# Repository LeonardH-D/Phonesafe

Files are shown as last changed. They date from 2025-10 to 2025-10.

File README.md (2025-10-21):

# Phonesafe
As many of us I have a (slight) smartphone addiction. To make it easier to withstand the distraction of it in lectures and working I designed this safe which is timer controlled and locks away your phone to get in the flow. 

A instructables with detailed building instructions will follow soon.

The code is written in the arduino IDE and still in beta. 

The box for the smartphone can be adjusted with Fusion 360 as the files are included. The attatched box is for an iPhone 15 Pro with a Mous Intralock case. 

In the PCB folder I uploaded the Gerber archive in Version 2. Version 2.1 will includes an external crystal for RTC will be uploaded soon. It will have the same dimensions as V2. 

The components are listed in the BOM. I sourced them in Germany at Reichelt and in China on Aliexpress. But all (exept the charging module) are pretty universally available, that should be no problem. Soldering is pretty straigth forward as is flashing the ESP. 

I hope you enjoy it and it helps you collect some phone free hours (maybe even days) :)

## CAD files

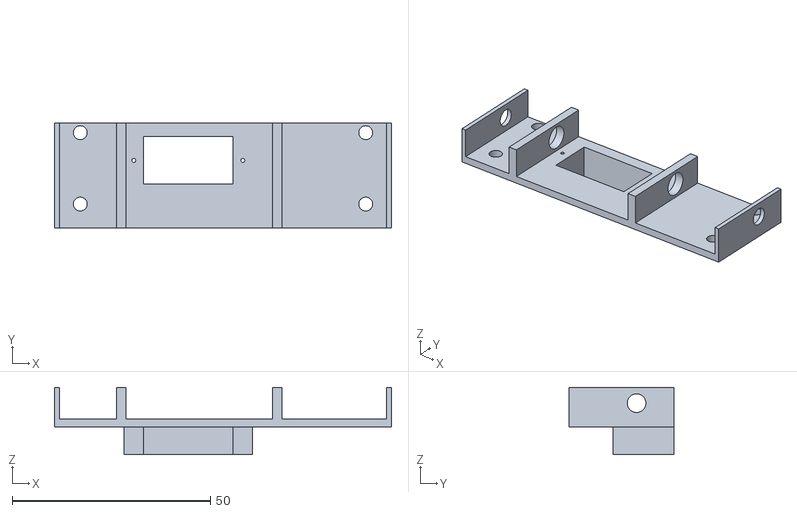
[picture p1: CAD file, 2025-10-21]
STLs/V2/Holder_Servo.stl
85.0 x 26.4 x 17.0

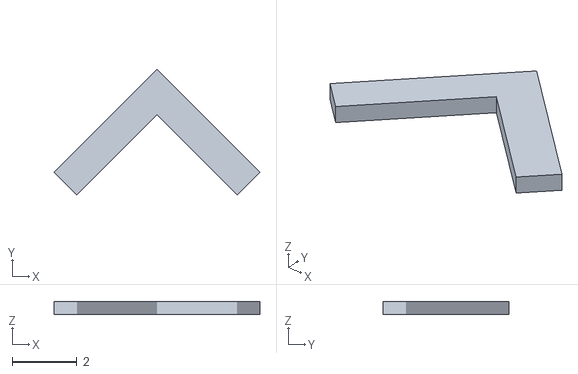
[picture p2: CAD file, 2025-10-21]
STLs/V2/Butto_UD_Arrow.stl
6.36 x 3.89 x 0.4

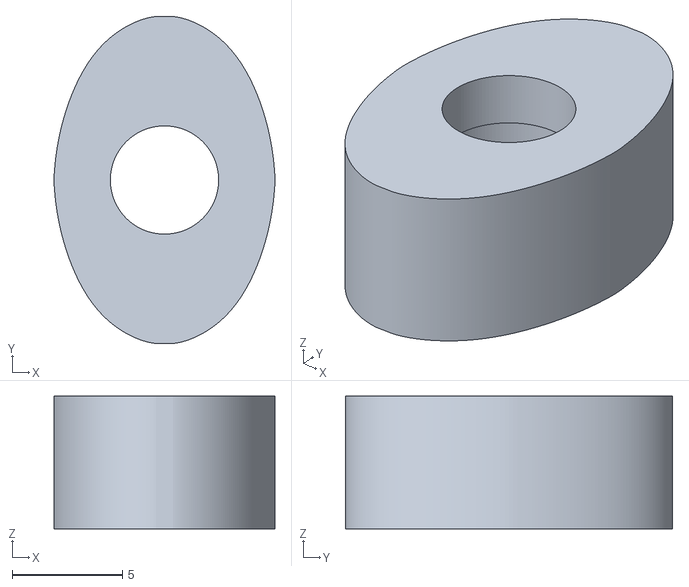
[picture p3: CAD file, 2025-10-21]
STLs/V2/Servo_Attachment.stl
10.0 x 14.8 x 6.00

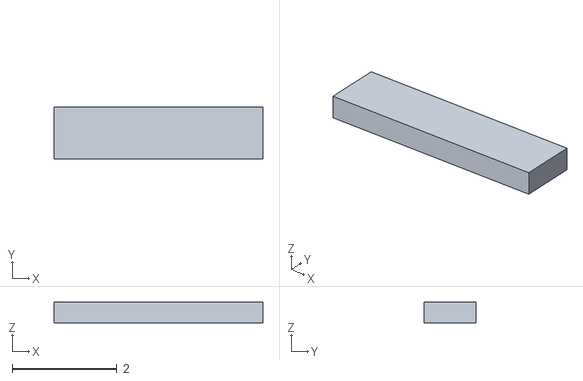
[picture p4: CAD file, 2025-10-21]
STLs/V2/Button_Menu_Up.stl
4.00 x 1.00 x 0.4

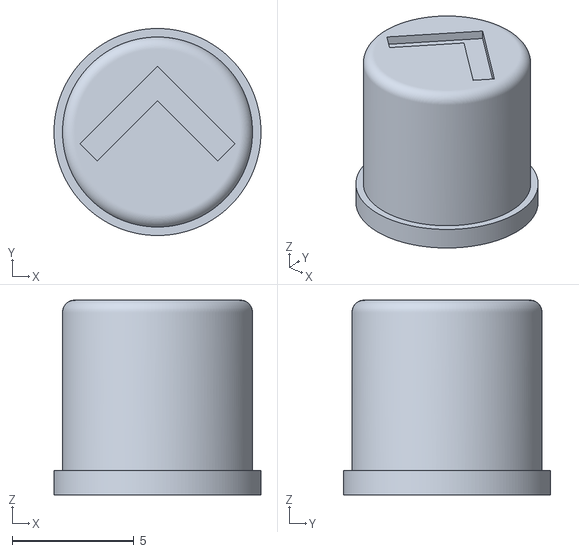
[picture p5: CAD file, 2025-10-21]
STLs/V2/Button_UD_Body.stl
8.50 x 8.50 x 8.00

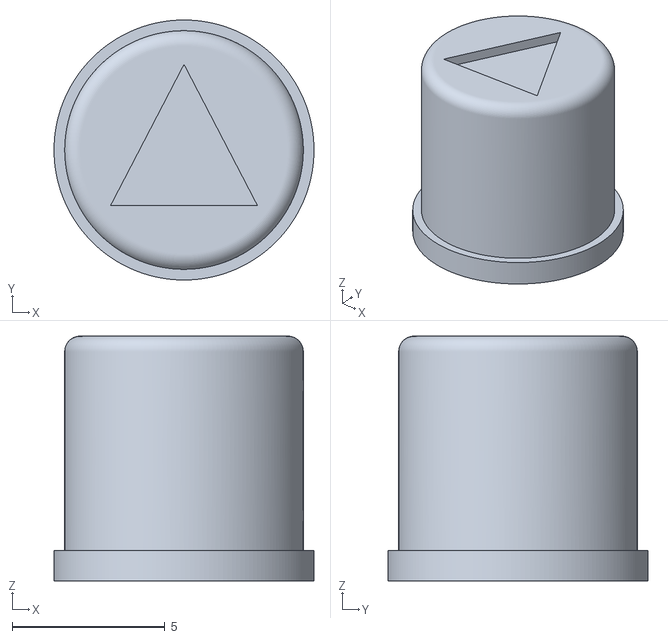
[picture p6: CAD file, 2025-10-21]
STLs/V2/Button_Start_Body.stl
8.50 x 8.50 x 8.00

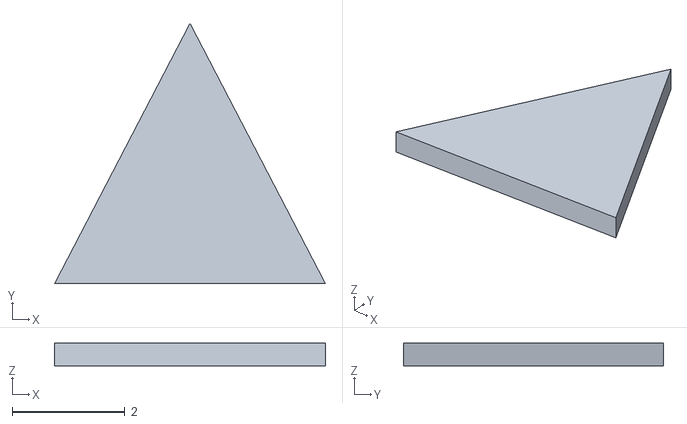
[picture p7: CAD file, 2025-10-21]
STLs/V2/Button_Start_Arrow.stl
4.80 x 4.61 x 0.4

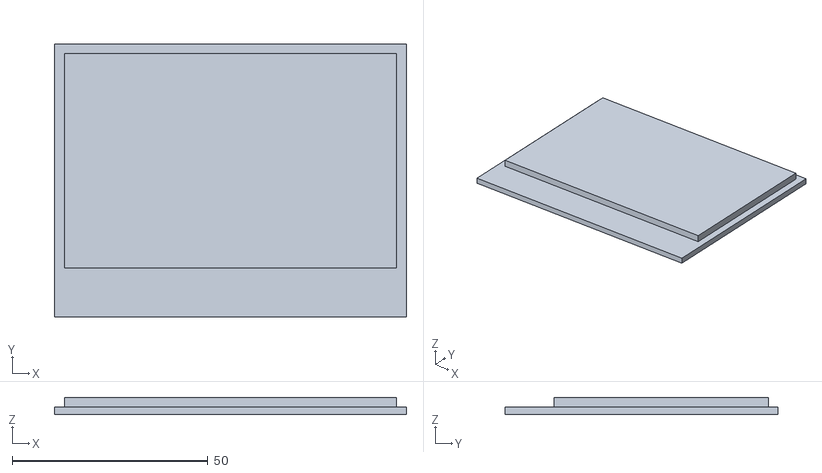
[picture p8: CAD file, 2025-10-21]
STLs/V2/Cover_PCB.stl
90.0 x 69.8 x 4.40

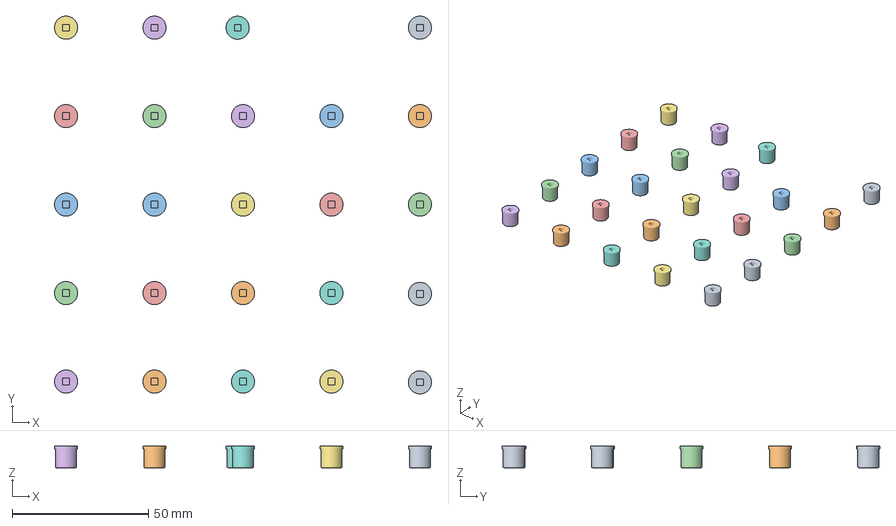
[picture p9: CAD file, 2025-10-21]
STLs/V2/Button_Menu_Body.3mf
138.5 x 138.8 x 8.00 mm
Knopf_Menu_Body x 6
Knopf_Start_Arrow x 6
Knopf_UD_Arrow x 12

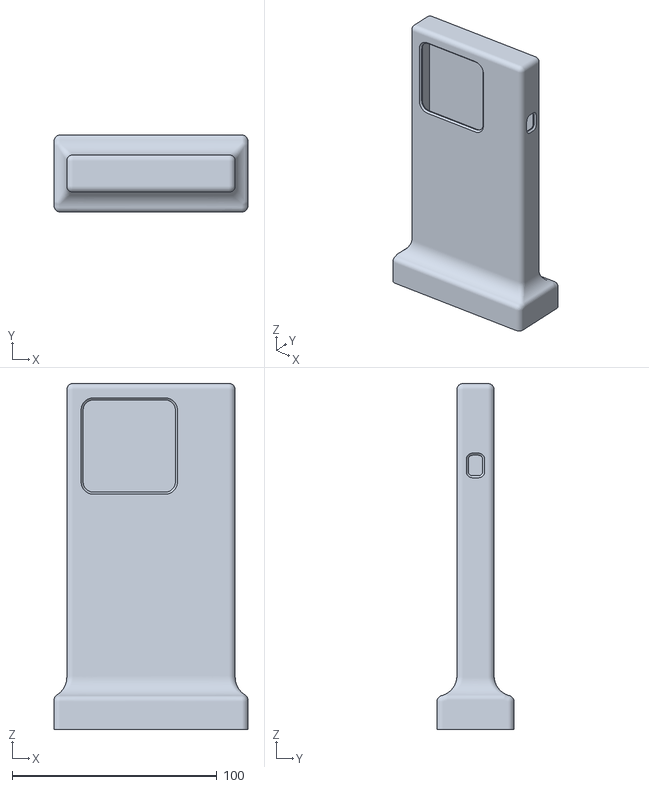
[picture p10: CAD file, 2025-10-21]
STLs/V2/Box_iP15P.stl
94.6 x 37.6 x 168.8

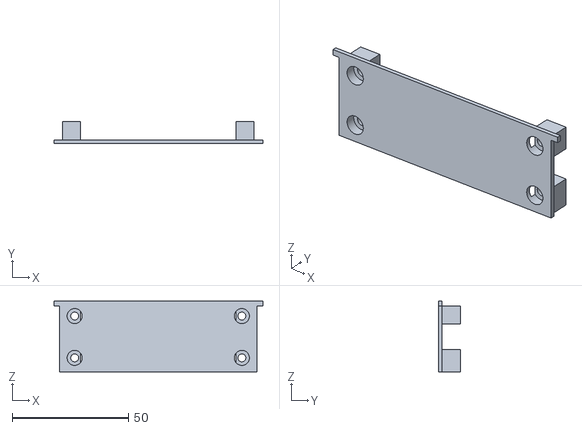
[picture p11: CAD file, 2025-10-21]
STLs/V2/Cover_locking_mechanism.stl
90.0 x 9.40 x 30.4

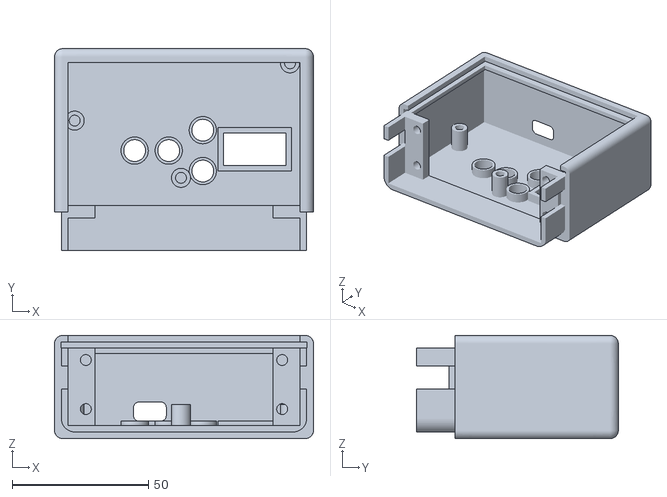
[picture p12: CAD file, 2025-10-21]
STLs/V2/Housing.stl
95.0 x 74.0 x 37.8

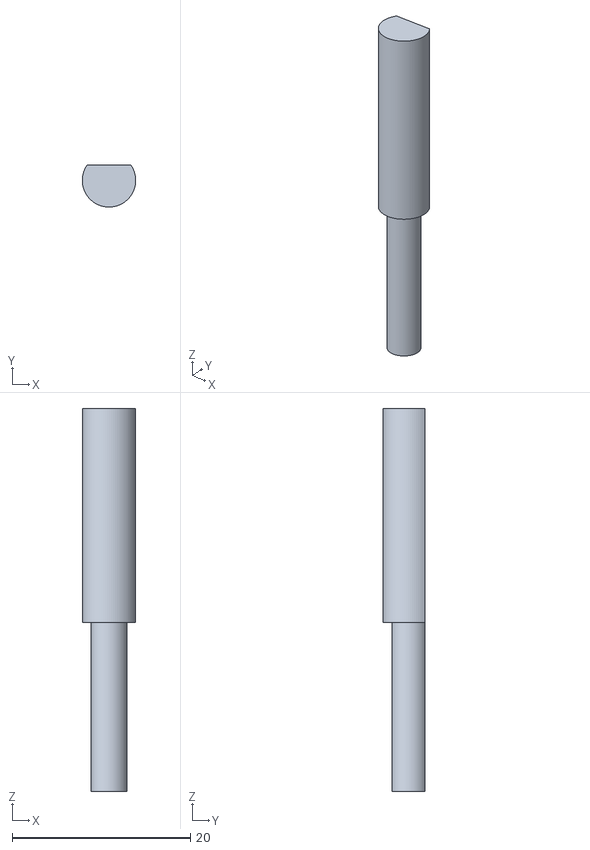
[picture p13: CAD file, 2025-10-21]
STLs/V2/Blockingbolt.stl
6.00 x 4.73 x 43.0

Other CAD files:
STLs/V2/Button_Menu_Middle.stl
STLs/V2/Button_Menu_Down.stl
STLs/V2/Button_Menu_Body.stl

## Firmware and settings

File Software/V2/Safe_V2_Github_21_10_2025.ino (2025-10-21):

#include <Wire.h>
#include "SSD1306Ascii.h"
#include "SSD1306AsciiWire.h"
#include <OneButton.h>
#include <ESP32Servo.h>
#include <Preferences.h>
#include <math.h>
#include "esp_sleep.h"
#include <WiFi.h>
#include <WebServer.h>
#include <time.h>
#include <sys/time.h>
#include <string.h>
#include <stdlib.h>
#include "driver/gpio.h"

// ============================================================================
//  External 32 kHz RTC clock – includes & guards
// ============================================================================
extern "C" {
  #if __has_include("rtc_clk.h")
    #include "rtc_clk.h"
  #endif
  #if __has_include("soc/rtc.h")
    #include "soc/rtc.h"
  #endif
}

// ============================================================================
//  Board / IO
// ============================================================================
#define LED_PIN (-1)         // disabled (SDA=8 is used for I2C on many C3 boards)
#define I2C_ADDRESS 0x3C
#define I2C_SDA 8
#define I2C_SCL 9

// Buttons
#define BTN_UP     5
#define BTN_DOWN   6
#define BTN_RESET  7
#define BTN_START  10

// Servo
#define SERVO_PIN 0

// Battery/VIN ADC pins (ESP32-C3 ADC1 channels)
#define BAT_ADC 1
#define VIN_ADC 2

// ============================================================================
//  Globals
// ============================================================================
SSD1306AsciiWire oled;
OneButton btnUp(BTN_UP, true);
OneButton btnDown(BTN_DOWN, true);
OneButton btnReset(BTN_RESET, true);
OneButton btnStart(BTN_START, true);
Servo myServo;
int servoPos = 0;
Preferences prefs;
WebServer server(80);

// Timer
const unsigned long MAX_SECONDS = 359999UL; // 99:59:59
unsigned long countdownSeconds = 0;
unsigned long originalDuration = 0;
unsigned long lastUpdate = 0;
bool running = false;

// Mode
enum LockMode : uint8_t { MODE_RELATIVE = 0, MODE_ABSOLUTE = 1 };
LockMode lockMode = MODE_RELATIVE;
time_t unlockAt = 0;            // target (epoch, today)
time_t lockStartedAt = 0;       // when locking started (for absolute mode)
bool timeIsSet = false;

// Stats
unsigned long totalReclaimed = 0;

// Fast increment
bool fastIncrementUp = false;
bool fastIncrementDown = false;
unsigned long lastIncrementUp = 0;
unsigned long lastIncrementDown = 0;

// Display
char lastDisplay[9] = "00:00:00";
const uint8_t COL_CENTER_REL = 16;
const uint8_t COL_CENTER_ABS = 34;

// Power / sleep
const unsigned long INACTIVITY_MS = 60000UL;
unsigned long lastInteractionMs = 0;
bool displayIsOn = true;

// Absolute target (today)
int absHour = 0;
int absMin  = 0;

// Battery / VIN
const float R1 = 100000.0f, R2 = 100000.0f;
const float VOLT_DIV = (R1 + R2) / R2; // 2.0
const float CAL = 1.00f;
const unsigned long BATT_INTERVAL_MS = 3000;
const int BATT_SAMPLES = 12;
unsigned long lastBattMs = 0;
float lastBattV = -1.0f;
int lastBattPct = -1;

const float VR1 = 100000.0f, VR2 = 100000.0f;
const float VOLT_DIV_VIN = (VR1 + VR2) / VR2; // 2.0
const float CAL_VIN = 1.00f;
const unsigned long VIN_INTERVAL_MS = 2000;
const int VIN_SAMPLES = 10;
unsigned long lastVinMs = 0;
float lastVin = -1.0f;

// Charging detection interval (actual VIN in volts)
const float VIN_CHARGE_MIN = 3.30f;  // lower bound (e.g., node 1.7 V with 1:1 divider)
const float VIN_CHARGE_MAX = 5.6f;  // upper bound (protect against noise / mis-wire)
bool lastChargingShown = false;
bool isChargingNow = false;
float lastVinDisplay = 0.0f;  // Debug: store last measured VIN for OLED

// Menu
bool showMenu = false;
int menuIndex = 0;              // 0=Stats, 1=About, 2=Mode, 3=Clock, 4=Setup Portal
const int MENU_COUNT = 5;

// Persistence
const uint32_t CONFIG_MAGIC = 0xC0FFEE11;

// Wi-Fi / NTP
char wifiSsid[33] = {0};
char wifiPass[65] = {0};

int   lastNtpSyncYday   = -1;
time_t lastNtpSyncEpoch = 0;

const char* NTP_SERVER1 = "pool.ntp.org";
const char* TZ_STR      = "CET-1CEST,M3.5.0/2,M10.5.0/3";

// Preference keys
const char* KEY_WIFI_SSID = "wifi_ssid";
const char* KEY_WIFI_PASS = "wifi_pass";
const char* KEY_NTP_YDAY  = "ntp_yday";
const char* KEY_NTP_EPOCH = "ntp_epoch";
const char* KEY_LOCKSTART = "lockStart";     // persist lockStartedAt

// AP / Web
bool portalActive = false;
unsigned long portalStartedMs = 0;
const unsigned long PORTAL_TIMEOUT_MS = 300000UL;
const char* AP_SSID = "SafeSetup";
const char* AP_PASS = "12345678";

// External 32 kHz
bool ext32k_ok = false;

// ============================================================================
//  Prototypes
// ============================================================================
void enableExternal32K();
void noteInteraction();
void oledDisplayOn();
void oledDisplayOff();
void setupLightSleepWakePins();
void maybeEnterLightSleep();
void lockServo();
void unlockServo();

void clearRows(uint8_t row_from, uint8_t rows);
void print2XBlock(uint8_t rowTop, uint8_t col, const char* txt);
void displayMainHeader(int pct);
void displayTimeRel(bool force);
void displayTimeAbs(bool force);
void displayChargingLine();

float readBatteryVoltage();
float readVinVoltage();
int liionPercentFromVoltage(float v);

void showStatsPage();
void showMainPage();
void showAboutPage();
void showModePage();
void showClockPage();
void showPortalPage();
void renderMenuPage();


void startTimePortal();
void stopTimePortal();
void handleRoot();
void handleSet();
void handleWifi();

void setSystemEpoch(time_t nowEpoch);
time_t nowEpoch();

void absInitFromNowOrUnlock();
void absClampToToday();
time_t absMakeEpochToday();
void absAdjustMinutes(int delta);

void applyDefaultsAndSave(bool keepTotal);
void saveState();
void loadState();

void loadWifiCreds();
void saveWifiCreds();
bool connectWifiSTA(uint32_t timeoutMs);
bool syncTimeViaNtp(uint32_t waitMs);
void disconnectWifi();
void maybeHourlyNtpSync();

// ============================================================================
//  External 32 kHz
// ============================================================================
void enableExternal32K() {
#if defined(RTC_SLOW_FREQ_32K_XTAL) && defined(RTC_PLL_FREQ_480M)
  #if __has_include("rtc_clk.h")
    rtc_clk_32k_enable(true);
    bool stable = false;
    for (int i = 0; i < 200; ++i) {
      if (rtc_clk_32k_enabled()) { stable = true; break; }
      delay(10);
    }
    if (stable) {
      rtc_clk_slow_freq_set(RTC_SLOW_FREQ_32K_XTAL);
      ext32k_ok = true;
    } else {
      rtc_clk_32k_enable(false);
      rtc_clk_slow_freq_set(RTC_SLOW_FREQ_RTC);
      ext32k_ok = false;
    }
  #endif
#else
  ext32k_ok = false;
#endif
}

// ============================================================================
//  Web portal HTML (English)
// ============================================================================
const char PAGE_HTML[] PROGMEM = R"HTML(
<!doctype html><meta name=viewport content="width=device-width,initial-scale=1">
<title>Safe Setup Portal</title>
<style>
  body{font-family:sans-serif;margin:20px;max-width:560px}
  button,input{font-size:1rem;padding:.5rem .7rem}
  label{display:block;margin:.4rem 0 .2rem}
  .card{border:1px solid #ddd;border-radius:8px;padding:12px;margin:14px 0}
  .row{display:flex;gap:8px;align-items:center}
</style>

<h2>System Time & Wi-Fi</h2>

<div class=card>
  <h3>Set System Time</h3>
  <p>This only sets the internal clock.</p>
  <button onclick="sendNow()">Use device time</button>
  <span id=resp style="margin-left:10px"></span>
</div>

<div class=card>
  <h3>Save Home Wi-Fi (for automatic hourly NTP sync)</h3>
  <label>SSID</label>
  <input id=ssid placeholder="Wi-Fi name" maxlength=32>
  <label>Password</label>
  <input id=pass type=password placeholder="Wi-Fi password" maxlength=64>
  <div class=row style="margin-top:.6rem">
    <button onclick="saveWifi()">Save</button>
    <span id=wifiResp></span>
  </div>
  <p style="font-size:.9rem;color:#555">Credentials are stored locally on the device.</p>
</div>

<script>
function epochSec(d){return Math.floor(d.getTime()/1000);}
function sendNow(){
  const now=epochSec(new Date());
  fetch('/set?now='+now).then(r=>r.text()).then(t=>{document.getElementById('resp').textContent=t}).catch(e=>alert(e));
}
function saveWifi(){
  const s=document.getElementById('ssid').value.trim();
  const p=document.getElementById('pass').value;
  fetch('/wifi?ssid='+encodeURIComponent(s)+'&pass='+encodeURIComponent(p))
    .then(r=>r.text()).then(t=>{document.getElementById('wifiResp').textContent=t})
    .catch(e=>alert(e));
}
</script>
)HTML";

// ============================================================================
//  Absolute mode helpers (today)
// ============================================================================
void absInitFromNowOrUnlock() {
  time_t now = nowEpoch();
  if (!timeIsSet || now <= 0) { absHour = 22; absMin = 0; return; }
  struct tm tmNow; localtime_r(&now, &tmNow);
  if (unlockAt > now) {
    struct tm tmTgt; time_t tgt=unlockAt; localtime_r(&tgt, &tmTgt);
    absHour = (tmTgt.tm_yday==tmNow.tm_yday)? tmTgt.tm_hour : tmNow.tm_hour;
    absMin  = (tmTgt.tm_yday==tmNow.tm_yday)? tmTgt.tm_min  : tmNow.tm_min;
  } else {
    absHour = tmNow.tm_hour; absMin = tmNow.tm_min;
  }
}

void absClampToToday() {
  time_t now = nowEpoch();
  if (!timeIsSet || now <= 0) {
    if (absHour < 0) absHour = 0;
    if (absHour > 23) absHour = 23;
    if (absMin  < 0) absMin  = 0;
    if (absMin  > 59) absMin  = 59;
    return;
  }
  struct tm tmNow; localtime_r(&now, &tmNow);
  int nowM = tmNow.tm_hour*60 + tmNow.tm_min;
  int tgtM = absHour*60 + absMin;
  if (tgtM < nowM) tgtM = nowM;
  if (tgtM > 23*60 + 59) tgtM = 23*60 + 59;
  absHour = tgtM / 60;
  absMin  = tgtM % 60;
}

time_t absMakeEpochToday() {
  time_t now = nowEpoch(); if (now <= 0) return 0;
  struct tm t; localtime_r(&now,&t);
  t.tm_sec = 0; t.tm_hour = absHour; t.tm_min  = absMin;
  return mktime(&t);
}

void absAdjustMinutes(int delta) {
  int tgtM = absHour*60 + absMin + delta;
  if (tgtM < 0) tgtM = 0;
  if (tgtM > 23*60 + 59) tgtM = 23*60 + 59;
  absHour = tgtM / 60;
  absMin  = tgtM % 60;
  absClampToToday();
}

// ============================================================================
//  Defaults / Persistence
// ============================================================================
void applyDefaultsAndSave(bool keepTotal) {
  unsigned long keepTotalVal = keepTotal ? prefs.getULong("total", 0UL) : 0UL;
  countdownSeconds = 0;
  originalDuration = 0;
  running = false;
  unlockAt = 0;
  lockStartedAt = 0;   // reset
  timeIsSet = false;
  lockMode = MODE_RELATIVE;
  servoPos = 0;
  totalReclaimed = keepTotalVal;
  absHour = 22; absMin = 0;
  prefs.putUInt("magic", CONFIG_MAGIC);
  saveState();
}

void saveState() {
  prefs.putULong("remain", countdownSeconds);
  prefs.putULong("orig", originalDuration);
  prefs.putBool("running", running);
  prefs.putULong("total", totalReclaimed);
  prefs.putUChar("srvpos", (uint8_t)servoPos);

  prefs.putUChar("mode", (uint8_t)lockMode);
  prefs.putULong("unlockAt", (uint32_t)unlockAt);
  prefs.putBool("timeSet", timeIsSet);
  prefs.putUInt("magic", CONFIG_MAGIC);

  // persist absolute-mode start
  prefs.putULong(KEY_LOCKSTART, (uint32_t)lockStartedAt);
}

void loadState() {
  countdownSeconds = prefs.getULong("remain", 0UL);
  originalDuration = prefs.getULong("orig", 0UL);
  running = prefs.getBool("running", false);
  totalReclaimed = prefs.getULong("total", 0UL);
  servoPos = (int)prefs.getUChar("srvpos", 0);

  lockMode = (LockMode)prefs.getUChar("mode", (uint8_t)MODE_RELATIVE);
  unlockAt = (time_t)prefs.getULong("unlockAt", 0UL);
  timeIsSet = prefs.getBool("timeSet", false);

  // restore absolute-mode start
  lockStartedAt = (time_t)prefs.getULong(KEY_LOCKSTART, 0UL);
}

// ============================================================================
//  Time helpers
// ============================================================================
void setSystemEpoch(time_t t) {
  struct timeval tv = { t, 0 };
  settimeofday(&tv, nullptr);
  timeIsSet = (t > 1600000000L);
}

time_t nowEpoch() { return time(nullptr); }

// ============================================================================
//  Wi-Fi / NTP
// ============================================================================
void loadWifiCreds() {
  String s = prefs.getString(KEY_WIFI_SSID, "");
  String p = prefs.getString(KEY_WIFI_PASS, "");
  memset(wifiSsid, 0, sizeof(wifiSsid));
  memset(wifiPass, 0, sizeof(wifiPass));
  s.toCharArray(wifiSsid, sizeof(wifiSsid));
  p.toCharArray(wifiPass, sizeof(wifiPass));
  lastNtpSyncYday  = (int)prefs.getInt(KEY_NTP_YDAY, -1);
  lastNtpSyncEpoch = (time_t)prefs.getULong(KEY_NTP_EPOCH, 0UL);
}

void saveWifiCreds() {
  prefs.putString(KEY_WIFI_SSID, wifiSsid);
  prefs.putString(KEY_WIFI_PASS, wifiPass);
}

bool connectWifiSTA(uint32_t timeoutMs) {
  if (wifiSsid[0] == '\0') return false;
  WiFi.mode(WIFI_STA);
  WiFi.begin(wifiSsid, wifiPass);
  uint32_t start = millis();
  while (WiFi.status() != WL_CONNECTED && millis() - start < timeoutMs) {
    delay(100);
  }
  return WiFi.status() == WL_CONNECTED;
}

bool syncTimeViaNtp(uint32_t waitMs) {
  // Timezone-safe NTP
  configTzTime(TZ_STR, NTP_SERVER1);

  uint32_t start = millis();
  time_t now = 0;
  do {
    delay(200);
    now = time(nullptr);
  } while ((now < 1600000000L) && (millis() - start < waitMs));

  if (now >= 1600000000L) {
    // Ensure TZ stays applied
    setenv("TZ", TZ_STR, 1);
    tzset();

    struct timeval tv = { now, 0 };
    settimeofday(&tv, nullptr);
    timeIsSet = true;
    lastNtpSyncEpoch = now;
    prefs.putULong(KEY_NTP_EPOCH, (uint32_t)lastNtpSyncEpoch);
    return true;
  }
  return false;
}

void disconnectWifi() {
  if (WiFi.getMode() != WIFI_OFF) {
    WiFi.disconnect(true);
    WiFi.mode(WIFI_OFF);
  }
}

// Hourly auto NTP sync (first 5 minutes each hour)
void maybeHourlyNtpSync() {
  static unsigned long lastCheckMs = 0;
  if (millis() - lastCheckMs < 30000UL) return;  // throttle our own CPU usage
  lastCheckMs = millis();

  // If you want to allow sync while locked, remove "|| running" below.
  if (portalActive /*|| running*/) return; 
  if (wifiSsid[0] == '\0') return;

  time_t now = nowEpoch();
  if (now <= 0) return;

  // Try if it's been an hour since last success
  if (lastNtpSyncEpoch > 0 && (now - lastNtpSyncEpoch) < 3600) return;

  // Bring up Wi-Fi briefly, sync, then go back down
  if (connectWifiSTA(8000)) {
    if (syncTimeViaNtp(8000)) {
      // Update "last sync" markers
      struct tm tmNow; localtime_r(&now, &tmNow);
      lastNtpSyncEpoch = now;
      lastNtpSyncYday = tmNow.tm_yday;
      prefs.putULong(KEY_NTP_EPOCH, (uint32_t)lastNtpSyncEpoch);
      prefs.putInt(KEY_NTP_YDAY, lastNtpSyncYday);
      saveState();
    }
    disconnectWifi();
  }
}

// ============================================================================
//  AP / Web
// ============================================================================
void startTimePortal() {
  if (portalActive) return;
  WiFi.mode(WIFI_AP);
  WiFi.softAP(AP_SSID, AP_PASS);
  delay(200);
  server.on("/", handleRoot);
  server.on("/set", handleSet);
  server.on("/wifi", handleWifi);
  server.begin();
  portalActive = true;
  portalStartedMs = millis();
  displayIsOn = true; oledDisplayOn();
}
void stopTimePortal() {
  if (!portalActive) return;
  server.stop();
  WiFi.softAPdisconnect(true);
  WiFi.mode(WIFI_OFF);
  portalActive = false;
}
void handleRoot() { server.send(200, "text/html", PAGE_HTML); }
void handleSet() {
  time_t now = server.hasArg("now") ? (time_t)server.arg("now").toInt() : 0;
  if (now > 1600000000L) {
    setSystemEpoch(now);
    prefs.putULong(KEY_NTP_EPOCH, (uint32_t)now);
    server.send(200, "text/plain", "System time set!");
  } else {
    server.send(400, "text/plain", "Invalid time");
  }
}
void handleWifi() {
  String ssid = server.hasArg("ssid") ? server.arg("ssid") : "";
  String pass = server.hasArg("pass") ? server.arg("pass") : "";
  ssid.trim();
  if (ssid.length() == 0) { server.send(400, "text/plain", "SSID missing"); return; }
  if (ssid.length() > 32 || pass.length() > 64) { server.send(400, "text/plain", "Too long"); return; }
  memset(wifiSsid, 0, sizeof(wifiSsid));
  memset(wifiPass, 0, sizeof(wifiPass));
  ssid.toCharArray(wifiSsid, sizeof(wifiSsid));
  pass.toCharArray(wifiPass, sizeof(wifiPass));
  saveWifiCreds();
  server.send(200, "text/plain", "Wi-Fi saved");
}

// ============================================================================
//  OLED helpers & pages
// ============================================================================
void clearRows(uint8_t row_from, uint8_t rows) {
  oled.set1X();
  for (uint8_t r = 0; r < rows; r++) {
    oled.setCursor(0, row_from + r);
    oled.print("                              ");
  }
}
void print2XBlock(uint8_t rowTop, uint8_t col, const char* txt) {
  clearRows(rowTop, 2);
  oled.set2X();
  oled.setCursor(col, rowTop);
  oled.print(txt);
  oled.set1X();
}

void displayChargingLine() {
  clearRows(7, 1);
  oled.set1X();
  oled.setCursor(0, 7);

  if (isChargingNow) {
    oled.printf("Charging", lastVinDisplay);
  } 
}

void displayMainHeader(int pct) {
  clearRows(1, 1);
  oled.set1X(); oled.setCursor(0,1);
  if (lockMode==MODE_RELATIVE) {
    oled.printf("%d%% | Timer", pct);
  } else {
    oled.printf("%d%% | Opens at...", pct);
  }
}
void displayTimeRel(bool forceUpdate) {
  unsigned long seconds = countdownSeconds;
  if (seconds > MAX_SECONDS) seconds = MAX_SECONDS;
  unsigned int h = seconds / 3600UL; seconds %= 3600UL;
  unsigned int m = seconds / 60UL;   unsigned int s = seconds % 60UL;
  char buf[9]; snprintf(buf, sizeof(buf), "%02u:%02u:%02u", h, m, s);
  if (forceUpdate || strcmp(buf, lastDisplay) != 0) {
    print2XBlock(3, COL_CENTER_REL, buf);
    strcpy(lastDisplay, buf);
  }
  clearRows(5,1);
  displayChargingLine();
}
void displayTimeAbs(bool force) {
  static int lastHr=-1, lastMin=-1; static bool lastRun=false;
  if (force || lastHr!=absHour || lastMin!=absMin || lastRun!=running) {
    char value[16]; snprintf(value,sizeof(value),"%02d:%02d", absHour, absMin);
    print2XBlock(3, COL_CENTER_ABS, value);
    lastHr=absHour; lastMin=absMin; lastRun=running;
  }
  clearRows(5,1);
  displayChargingLine();
}


void showStatsPage() {
  oled.clear();
  
  // use smaller font (4x6)
  oled.setFont(System5x7);   // default small readable font
  oled.set1X();
  
  oled.setCursor(0, 0);
  oled.println("Stats");
  oled.setCursor(0, 2);
  oled.println("Total time saved:");

  unsigned long total = totalReclaimed;
  unsigned long days  = total / 86400UL;
  unsigned long rem   = total % 86400UL;
  unsigned int  hours = rem / 3600UL;
  unsigned int  mins  = (rem % 3600UL) / 60UL;

  // draw in smaller size (1X) — no double-size here
  oled.setCursor(0, 4);
  oled.printf("%03lu days", days);
  oled.setCursor(0, 5);
  oled.printf("%02u hours", hours);
  oled.setCursor(0, 6);
  oled.printf("%02u mins", mins);

  // Always show VIN/charging line on bottom
  displayChargingLine();

  // Restore normal font for next pages
  oled.setFont(Adafruit5x7);
}
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
void loop() {
  btnUp.tick(); btnDown.tick(); btnReset.tick(); btnStart.tick();

  if (digitalRead(BTN_UP)==LOW || digitalRead(BTN_DOWN)==LOW ||
      digitalRead(BTN_RESET)==LOW || digitalRead(BTN_START)==LOW) {
    noteInteraction();
  }

  if (portalActive) {
    server.handleClient();
    if (millis() - portalStartedMs > PORTAL_TIMEOUT_MS) {
      stopTimePortal();
      if (showMenu) renderMenuPage(); else showMainPage();
    }
  }

  // Relative mode
  if (!showMenu && running && lockMode == MODE_RELATIVE) {
    if (millis() - lastUpdate >= 1000UL) {
      lastUpdate += 1000UL;
      if (countdownSeconds > 0) {
        countdownSeconds--;
        if (displayIsOn) displayTimeRel(false);
        saveState();
      } else {
        running = false;
        if (originalDuration > 0) { totalReclaimed += originalDuration; originalDuration = 0; }
        unlockServo();
        if (displayIsOn) displayTimeRel(true);
        saveState();
      }
    }
  }

  // Absolute mode
  if (!showMenu && lockMode == MODE_ABSOLUTE) {
    static unsigned long lastTick = 0;
    if (millis() - lastTick >= 250UL) {
      lastTick += 250UL;
      if (!running) absClampToToday();
      if (displayIsOn) displayTimeAbs(false);
    }
    if (running) {
      time_t now = nowEpoch();
      if (timeIsSet && unlockAt > 0 && now >= unlockAt) {
        running = false;
        unlockServo();

        // Add absolute-mode locked duration to stats
        if (lockStartedAt > 0 && unlockAt > lockStartedAt) {
          unsigned long duration = (unsigned long)(unlockAt - lockStartedAt);
          totalReclaimed += duration;
          lockStartedAt = 0;
          saveState();
        } else {
          saveState();
        }

        displayTimeAbs(true);
      }
    }
  }

  // Battery update
  if (!showMenu && displayIsOn && millis() - lastBattMs >= BATT_INTERVAL_MS) {
    lastBattMs = millis();
    float vbat = readBatteryVoltage();
    int pct = liionPercentFromVoltage(vbat);
    if (lastBattPct != pct) { lastBattV = vbat; lastBattPct = pct; displayMainHeader(pct); }
  }

  // VIN + charging hysteresis
if (!showMenu && displayIsOn && millis() - lastVinMs >= VIN_INTERVAL_MS) {
  lastVinMs = millis();
  float vin = readVinVoltage();
  lastVin = vin;
  lastVinDisplay = vin;   // ✅ store for display

  bool chargingNow = (vin >= VIN_CHARGE_MIN && vin <= VIN_CHARGE_MAX);

  if (chargingNow != isChargingNow) {
    isChargingNow = chargingNow;
    displayChargingLine();      // refresh OLED line 7
    lastChargingShown = isChargingNow;
  }
}

  // Display off after inactivity
  if (displayIsOn && (millis() - lastInteractionMs >= INACTIVITY_MS)) {
    oledDisplayOff(); displayIsOn = false;
  }

  // Light sleep when idle and no portal
  if (!running && !portalActive) {
    maybeEnterLightSleep();
  }

  // Hourly NTP sync attempt
  maybeHourlyNtpSync();
}

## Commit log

2025-10-21 Expand README with project details and instructions
    Added more details about the project, including instructions, code status, box adjustments, PCB version, components sourcing, and soldering information.
2025-10-21 Gerber files for V2
2025-10-21 Revise PCB details and add Gerber archive info
    Updated PCB information and added details about the Gerber archive.
